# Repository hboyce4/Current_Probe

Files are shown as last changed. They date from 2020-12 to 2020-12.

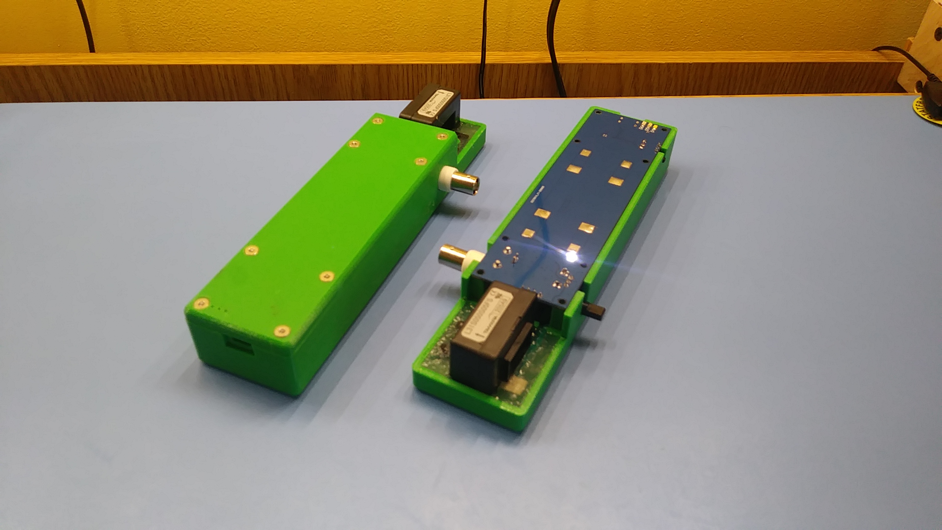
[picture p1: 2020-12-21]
Photos/20201220_143055.jpg

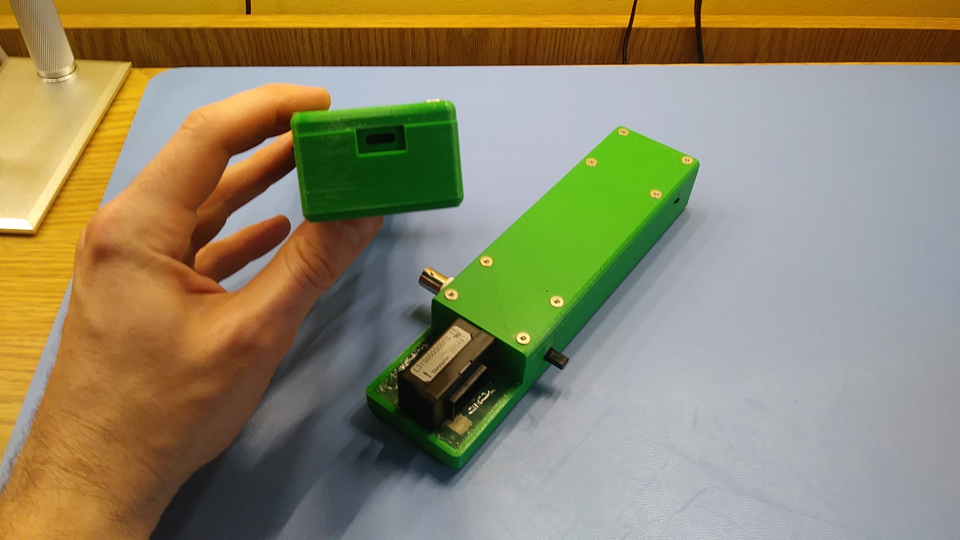
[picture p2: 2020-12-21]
Photos/20201220_143459.jpg

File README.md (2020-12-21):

Current_Probe

A poor man's current probe

Quick specs:

Sensor rated at +-50A nominal, although according to the datasheet it will easily do +-100A. The rest of the circuit is designed for +-100A.
Bandwidth: DC to 100kHz (-3dB) dictated by the sensor.
Batteries: 2P1S 18650 li-ion. 500mA charging current via USB.
Sensivity: 10A/V
Output impedance: 50ohms

Free to use for educational/hobby purposes

Hugo Boyce

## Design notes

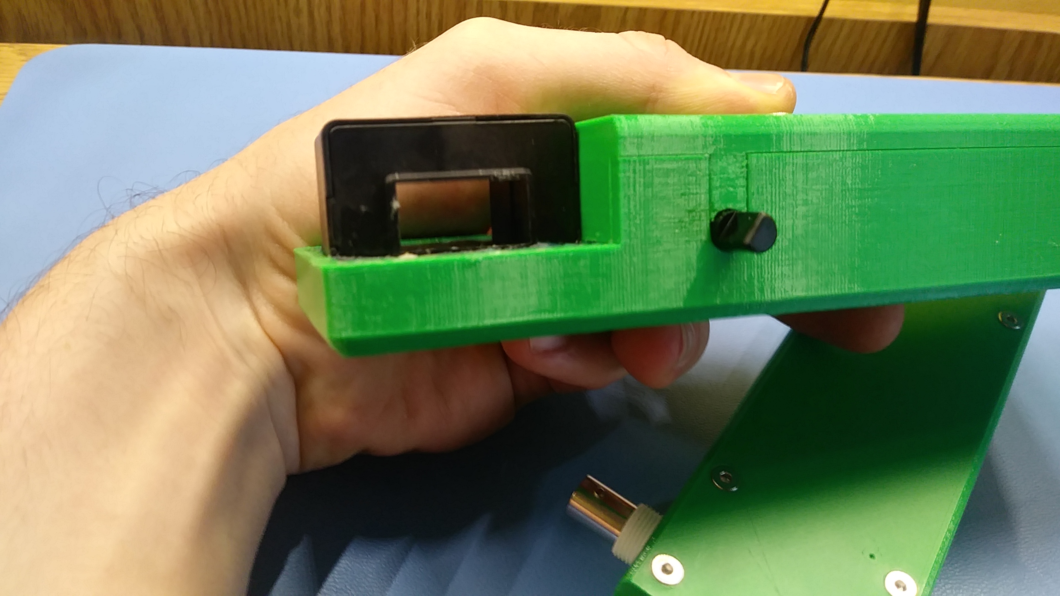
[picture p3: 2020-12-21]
Photos/20201220_143514_HDR.jpg

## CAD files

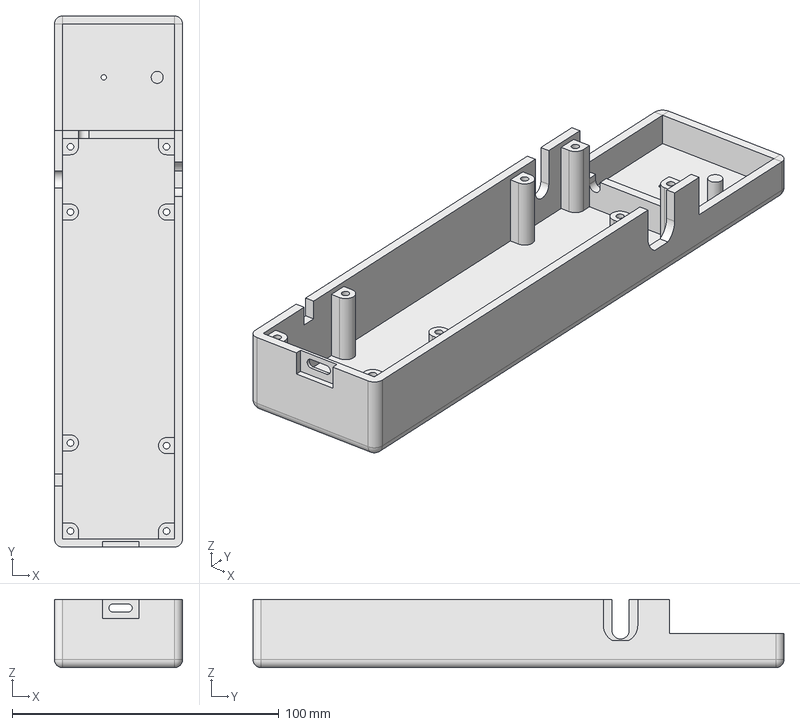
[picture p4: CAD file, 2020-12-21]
Enclosure/Bottom_half.step
48.0 x 199.0 x 25.6 mm

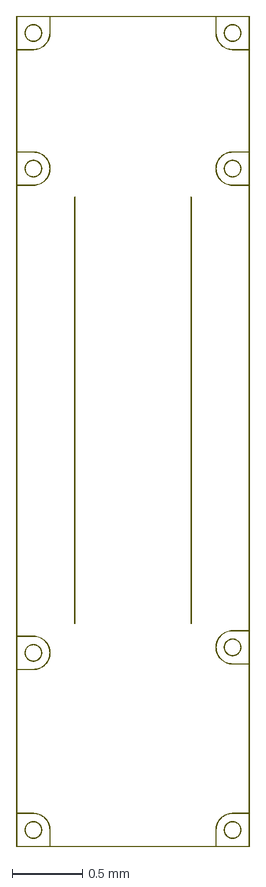
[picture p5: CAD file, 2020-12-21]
Enclosure/PCB - Current_Probe_V0.1_Mechanical_outline.dxf
1.66 x 5.91 mm

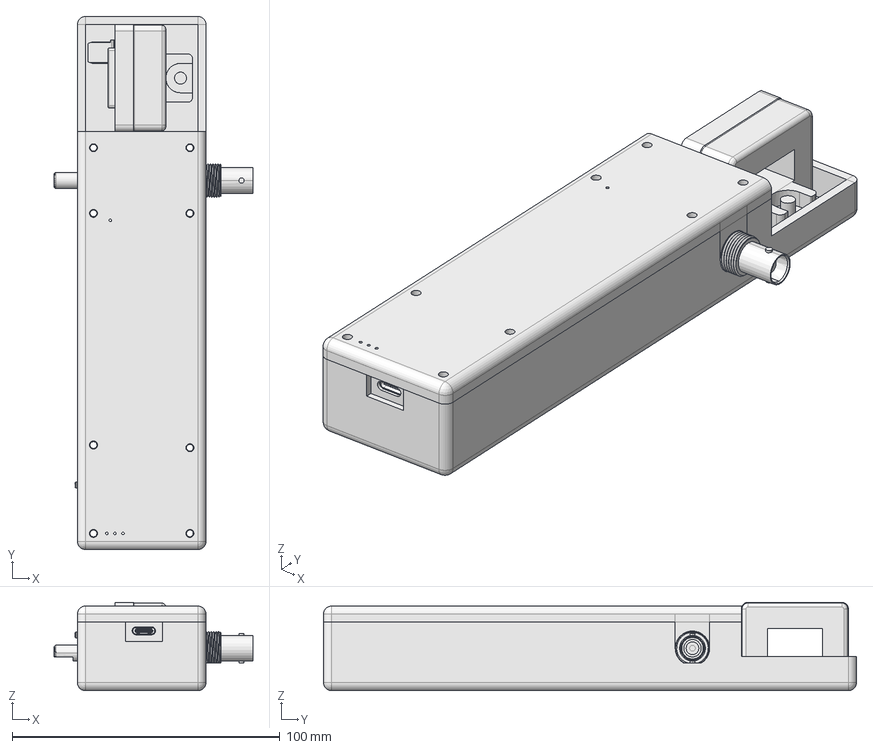
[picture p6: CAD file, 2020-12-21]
Enclosure/Current_Probe_EnclosureV0.1.5.FCStd
74.3 x 199.0 x 33.0 mm
Bottom_half
Board
Open_CASCADE_STEP_translator_6.8_2.1.1
lead
lead001
Open_CASCADE_STEP_translator_6.8_2.1.002
lead002
lead003
Open_CASCADE_STEP_translator_6.8_2.1
Open_CASCADE_STEP_translator_6.8_2.2.1
Thermal_Shape
Open_CASCADE_STEP_translator_6.8_2.4.1
Open_CASCADE_STEP_translator_6.8_2.4.002
Open_CASCADE_STEP_translator_6.8_2.4.003
Open_CASCADE_STEP_translator_6.8_2.4.004
Open_CASCADE_STEP_translator_6.8_2.4.005
Open_CASCADE_STEP_translator_6.8_2.4.006
Open_CASCADE_STEP_translator_6.8_2.4.007
Open_CASCADE_STEP_translator_6.8_2.4.008
Open_CASCADE_STEP_translator_6.8_2.4.009
Open_CASCADE_STEP_translator_6.8_2.4.010
Open_CASCADE_STEP_translator_6.8_1.1
Open_CASCADE_STEP_translator_6.8_1.2.1
Thermal_Shape001
Open_CASCADE_STEP_translator_6.8_1.4.1
Open_CASCADE_STEP_translator_6.8_1.4.002
Open_CASCADE_STEP_translator_6.8_1.4.003
Open_CASCADE_STEP_translator_6.8_1.4.004
Open_CASCADE_STEP_translator_6.8_1.4.005
Open_CASCADE_STEP_translator_6.8_1.4.006
Open_CASCADE_STEP_translator_6.8_1.4.007
Open_CASCADE_STEP_translator_6.8_1.4.008
Open_CASCADE_STEP_translator_6.8_1.4.009
Open_CASCADE_STEP_translator_6.8_1.4.010
Open_CASCADE_STEP_translator_6.8_1.4.011
Open_CASCADE_STEP_translator_6.8_1.4.012
Open_CASCADE_STEP_translator_6.8_1.4.013
Open_CASCADE_STEP_translator_6.8_1.4.014
Open_CASCADE_STEP_translator_6.8_1.4.015
Open_CASCADE_STEP_translator_6.8_1.4.016
Open_CASCADE_STEP_translator_6.8_1.4.017
Open_CASCADE_STEP_translator_6.8_1.4.018
Open_CASCADE_STEP_translator_6.8_1.4.019
Open_CASCADE_STEP_translator_6.8_1.4.020
Open_CASCADE_STEP_translator_6.8_1.4.021
Open_CASCADE_STEP_translator_6.8_1.4.022
Open_CASCADE_STEP_translator_6.8_1.4.023
Open_CASCADE_STEP_translator_6.8_1.4.024
Keystone-254-Battery_Clip
Keystone-254-Battery_Clip001
Keystone-254-Battery_Clip002
Keystone-254-Battery_Clip003
Extruded
Extruded001
Extruded002
Extruded003
Extruded004
Extruded005
Extruded006
Extruded007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

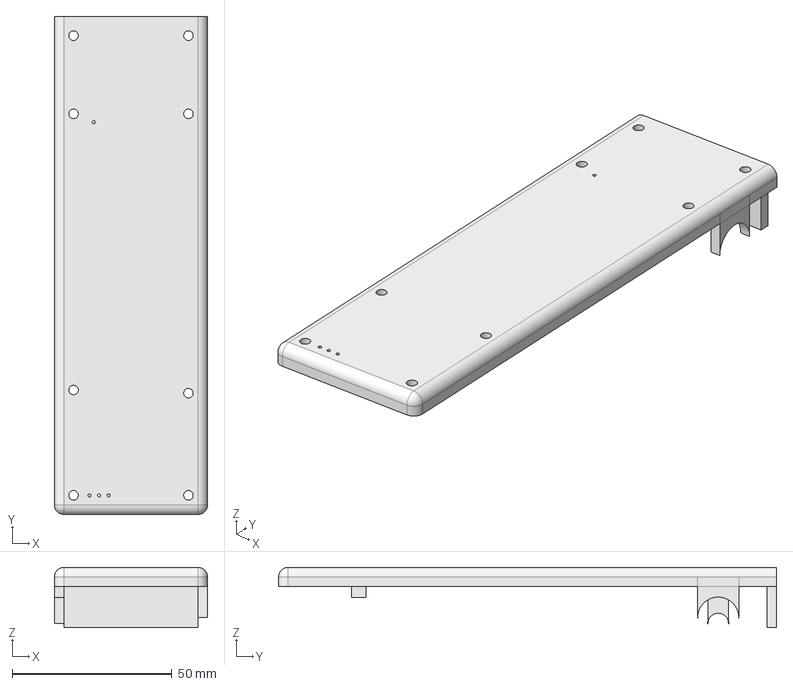
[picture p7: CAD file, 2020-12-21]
Enclosure/Top_half.step
48.0 x 156.0 x 18.9 mm

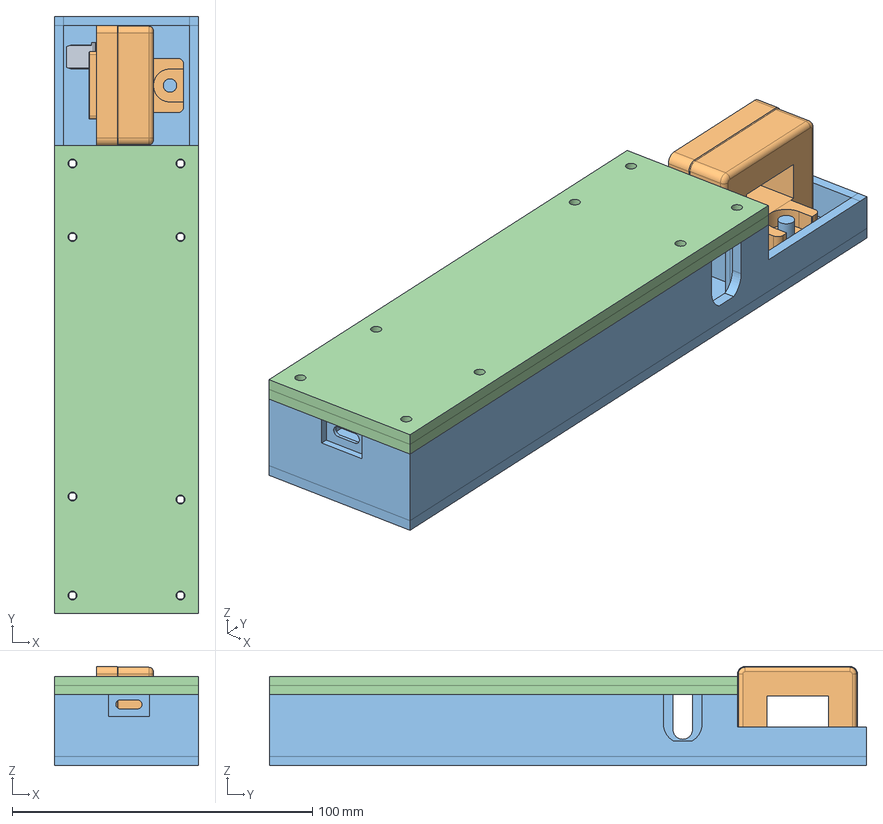
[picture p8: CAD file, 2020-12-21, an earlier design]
Enclosure/Current_Probe_EnclosureV0.1.FCStd
48.0 x 199.0 x 33.0 mm
Bottom_half
Top_half

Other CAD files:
Enclosure/PCB_DXF_With_measurements.FCStd
Enclosure/Bottom_half.stl
Enclosure/Top_half.stl

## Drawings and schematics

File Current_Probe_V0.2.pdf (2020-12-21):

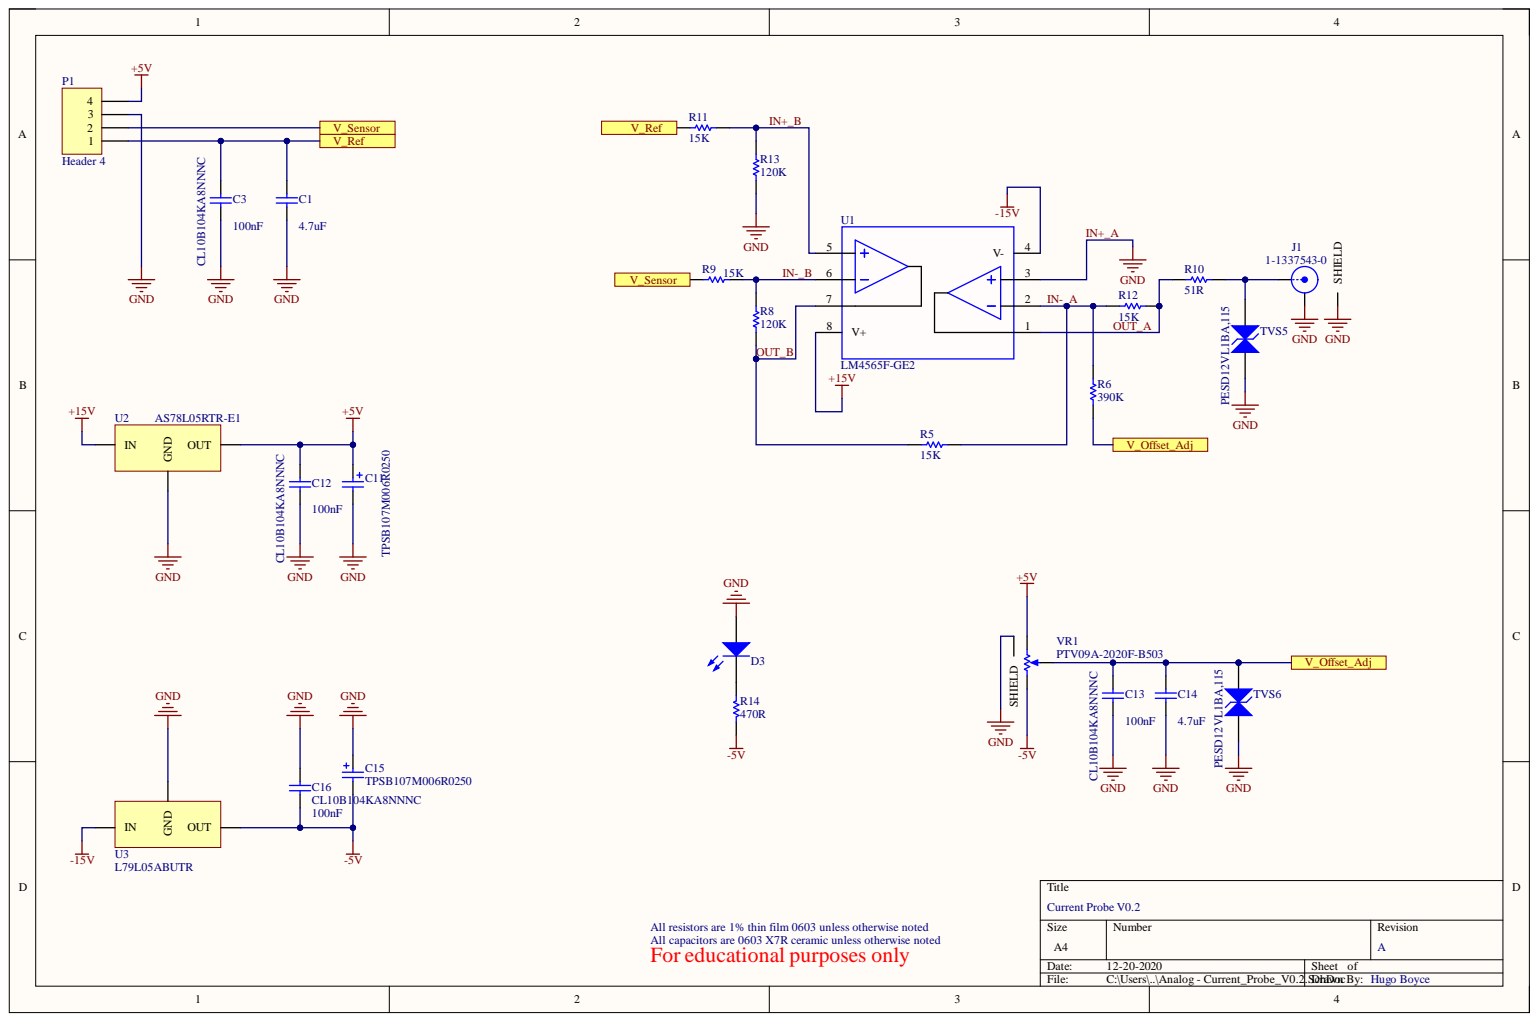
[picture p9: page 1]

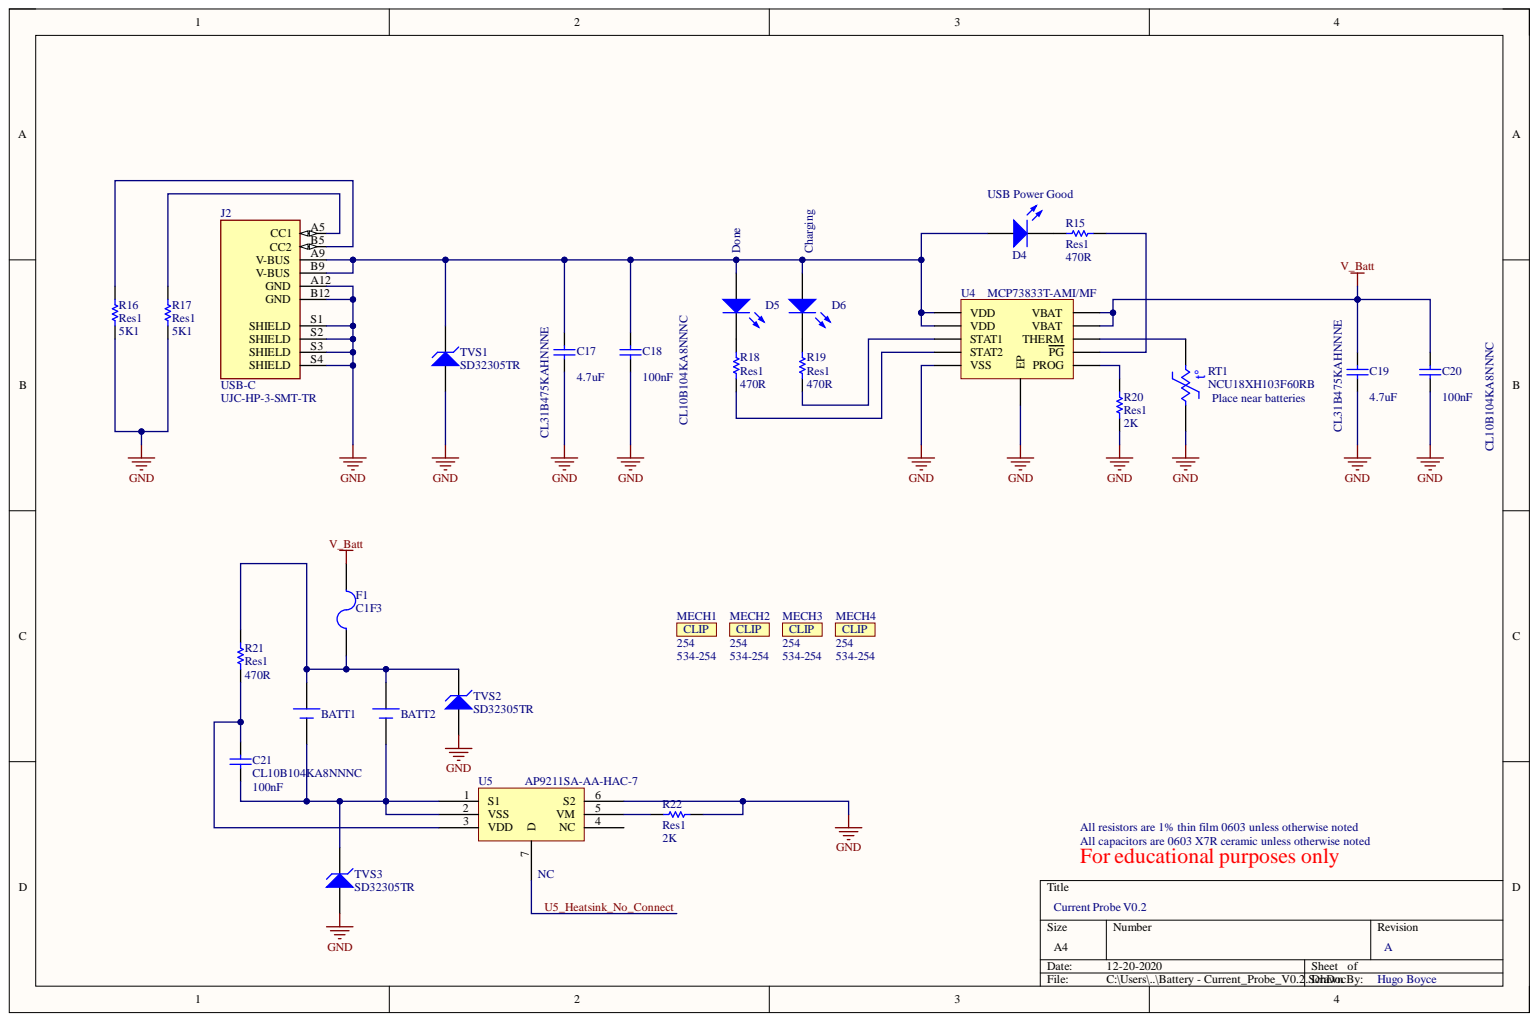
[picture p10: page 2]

2 | | R2 2

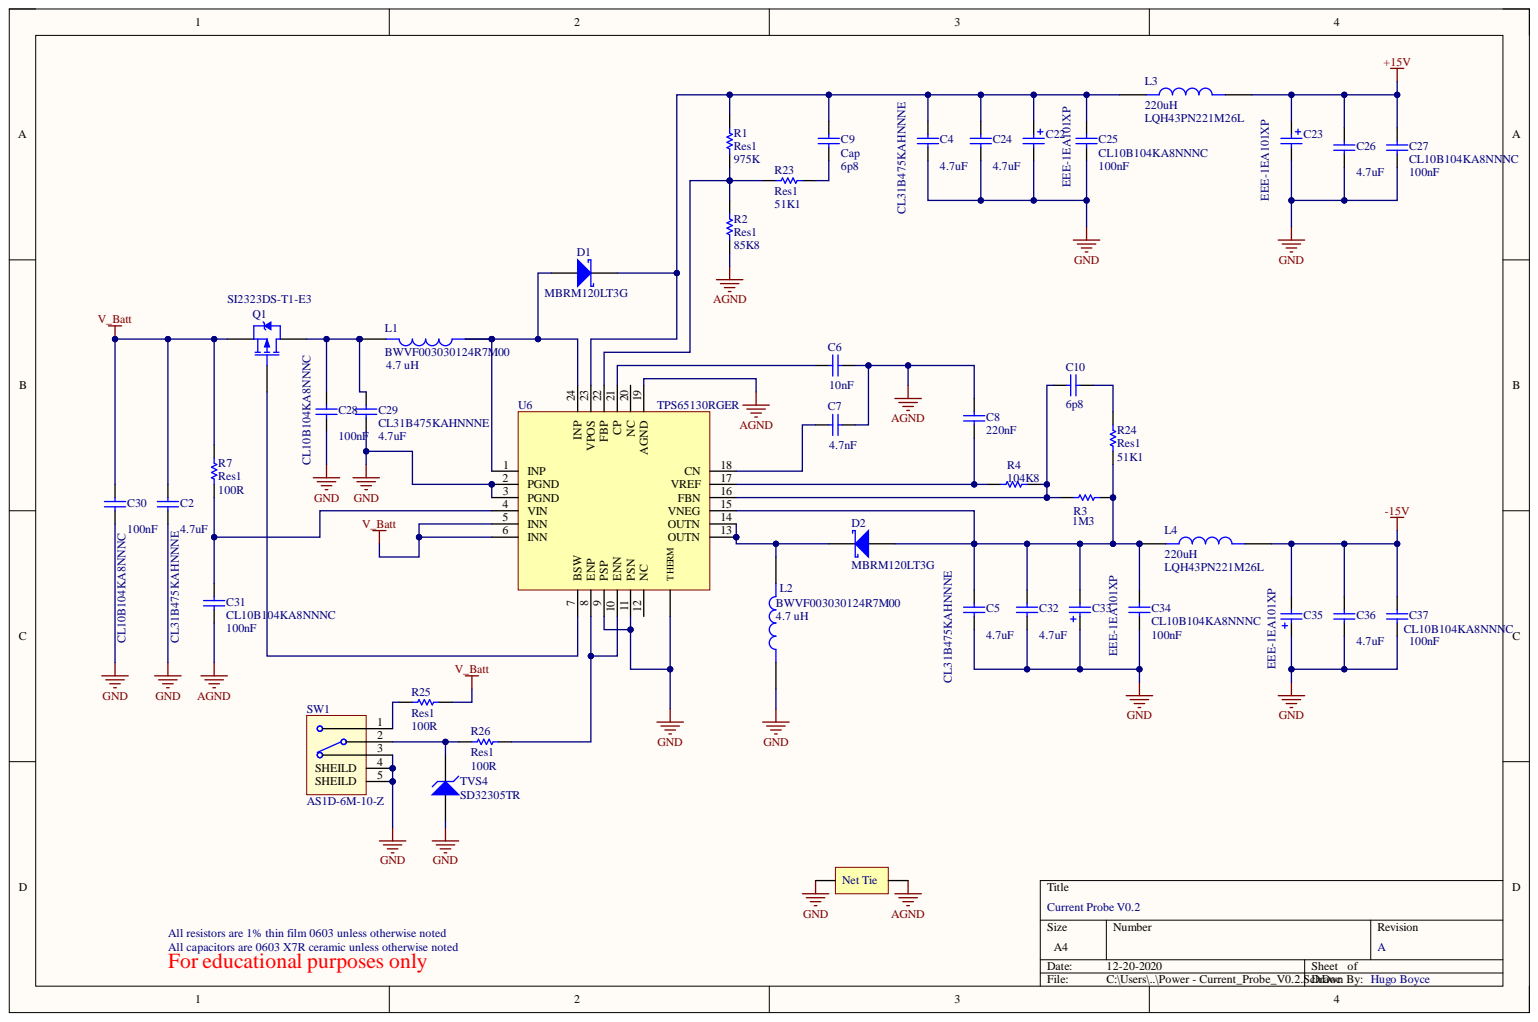
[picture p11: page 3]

AGND 19 NC 20 CP 21 FBP 22 VPOS 23 INP 24

PGND 2 | | 13 OUTN 14 VNEG 15 FBN 16 VREF 17 CN 18

INP 1 | OUTN

Res1 100R

INN 5
INN 6

All resistors are 1% thin film 0603 unless otherwise noted
All capacitors are 0603 X7R ceramic unless otherwise noted

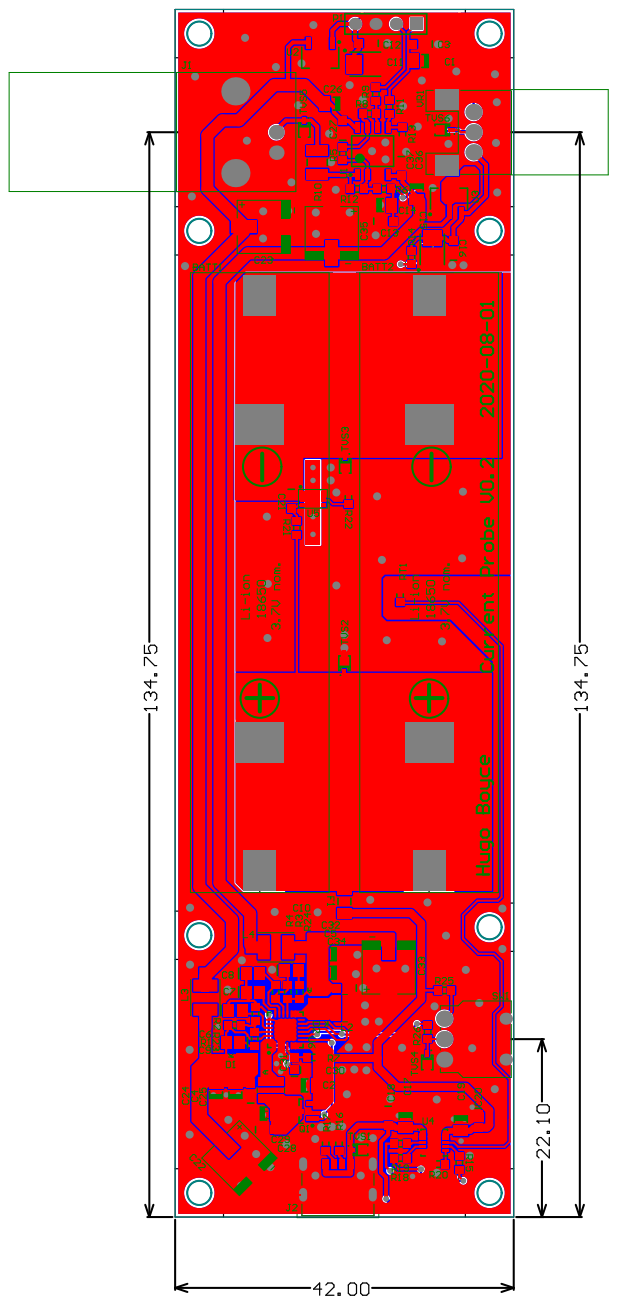
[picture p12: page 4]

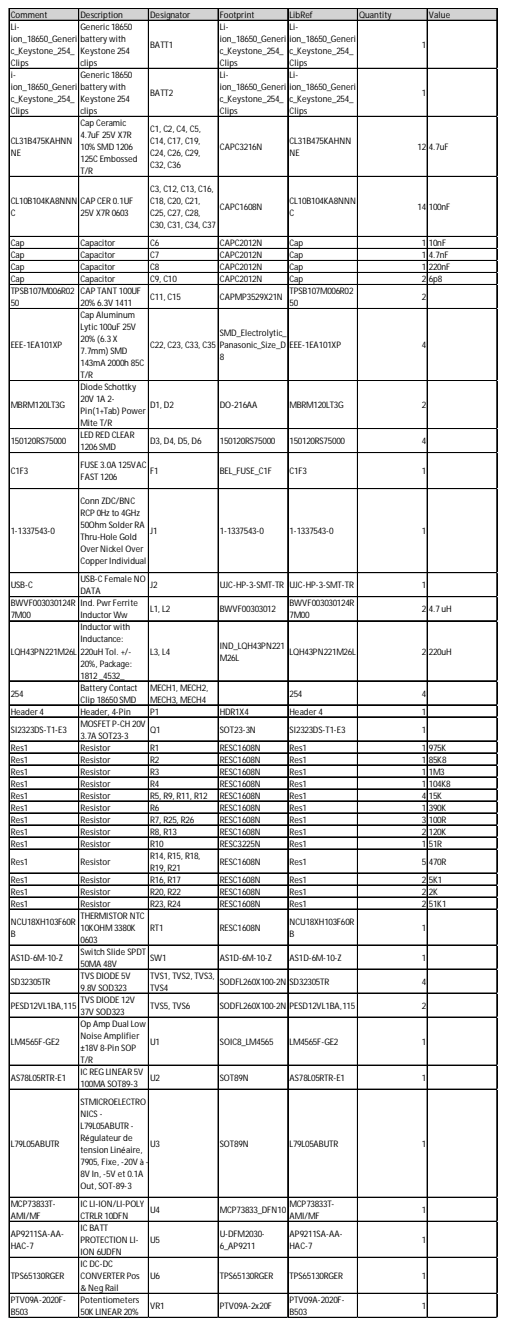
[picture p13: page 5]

Comment | Description | Designator | Footprint | LibRef | Quantity | Value
Li-ion_18650_Generi c_Keystone_254_ Clips | Generic 18650 battery with Keystone 254 clips | BATT1 | Li-ion_18650_Generi c_Keystone_254_ Clips | Li-ion_18650_Generi c_Keystone_254_ Clips

i-ion_18650_Generi c_Keystone_254_ Clips | Generic 18650 battery with Keystone 254 clips | BATT2 | Li-ion_18650_Generi c_Keystone_254_ Clips | Li-ion_18650_Generi c_Keystone_254_ Clips | 1

CL31B475KAHNN NE | Cap Ceramic 4.7uF 25V X7R 10% SMD 1206 125C Embossed T/R | C1, C2, C4, C5, C14, C17, C19, C24, C26, C29, C32, C36 | CAPC3216N | CL31B475KAHNN NE | 12 4.7uF

CL10B104KA8NNN C | CAP CER 0.1UF 25V X7R 0603 | C3, C12, C13, C16, C18, C20, C21, C25, C27, C28, C30, C31, C34, C37 | CAPC1608N | CL10B104KA8NNN C | 14 100nF

Cap | Capacitor | C6 | CAPC2012N | Cap | 1 10nF
Cap | Capacitor | C7 | CAPC2012N | Cap | 1 4.7nF
Cap | Capacitor | C8 | CAPC2012N | Cap | 1 220nF
Cap | Capacitor | C9, C10 | CAPC2012N | Cap | 2 6p8
TPSB107M006R02 50 | CAP TANT 100UF 20% 6.3V 1411 | C11, C15 | CAPMP3529X21N | TPSB107M006R02 50 | 2

EEE-1EA101XP | Cap Aluminum Lytic 100uF 25V 20% (6.3 X 7.7mm) SMD 143mA 2000h 85C T/R | C22, C23, C33, C35 | SMD_Electrolytic_ Panasonic_Size_D 8 | EEE-1EA101XP | 4

MBRM120LT3G | Diode Schottky 20V 1A 2-Pin(1+Tab) Power Mite T/R | D1, D2 | DO-216AA | MBRM120LT3G | 2

150120RS75000 | LED RED CLEAR 1206 SMD | D3, D4, D5, D6 | 150120RS75000 | 150120RS75000 | 4

C1F3 | FUSE 3.0A 125VAC FAST 1206 | F1 | BEL_FUSE_C1F | C1F3 | 1

1-1337543-0 | Conn ZDC/BNC RCP 0Hz to 4GHz 50Ohm Solder RA Thru-Hole Gold Over Nickel Over Copper Individual | J1 | 1-1337543-0 | 1-1337543-0 | 1

USB-C | USB-C Female NO DATA | J2 | UJC-HP-3-SMT-TR | UJC-HP-3-SMT-TR | 1

BWVF003030124R 7M00 | Ind. Pwr Ferrite Inductor Ww | L1, L2 | BWVF00303012 | BWVF003030124R 7M00 | 2 4.7 uH

LQH43PN221M26L | Inductor with Inductance: 220uH Tol. +/-20%, Package: 1812 _4532_ | L3, L4 | IND_LQH43PN221 M26L | LQH43PN221M26L | 2 220uH

254 | Battery Contact Clip 18650 SMD | MECH1, MECH2, MECH3, MECH4 | | 254 | 4

Header 4 | Header, 4-Pin | P1 | HDR1X4 | Header 4 | 1
SI2323DS-T1-E3 | MOSFET P-CH 20V 3.7A SOT23-3 | Q1 | SOT23-3N | SI2323DS-T1-E3 | 1

Res1 | Resistor | R1 | RESC1608N | Res1 | 1 975K
Res1 | Resistor | R2 | RESC1608N | Res1 | 1 85K8
Res1 | Resistor | R3 | RESC1608N | Res1 | 1 1M3
Res1 | Resistor | R4 | RESC1608N | Res1 | 1 104K8
Res1 | Resistor | R5, R9, R11, R12 | RESC1608N | Res1 | 4 15K
Res1 | Resistor | R6 | RESC1608N | Res1 | 1 390K
Res1 | Resistor | R7, R25, R26 | RESC1608N | Res1 | 3 100R
Res1 | Resistor | R8, R13 | RESC1608N | Res1 | 2 120K
Res1 | Resistor | R10 | RESC3225N | Res1 | 1 51R
Res1 | Resistor | R14, R15, R18, R19, R21 | RESC1608N | Res1 | 5 470R

Res1 | Resistor | R16, R17 | RESC1608N | Res1 | 2 5K1
Res1 | Resistor | R20, R22 | RESC1608N | Res1 | 2 2K
Res1 | Resistor | R23, R24 | RESC1608N | Res1 | 2 51K1
NCU18XH103F60R B | THERMISTOR NTC 10KOHM 3380K 0603 | RT1 | RESC1608N | NCU18XH103F60R B | 1

AS1D-6M-10-Z | Switch Slide SPDT 50MA 48V | SW1 | AS1D-6M-10-Z | AS1D-6M-10-Z | 1

SD32305TR | TVS DIODE 5V 9.8V SOD323 | TVS1, TVS2, TVS3, TVS4 | SODFL260X100-2N | SD32305TR | 4

PESD12VL1BA,115 | TVS DIODE 12V 37V SOD323 | TVS5, TVS6 | SODFL260X100-2N | PESD12VL1BA,115 | 2

LM4565F-GE2 | Op Amp Dual Low Noise Amplifier ±18V 8-Pin SOP T/R | U1 | SOIC8_LM4565 | LM4565F-GE2 | 1

AS78L05RTR-E1 | IC REG LINEAR 5V 100MA SOT89-3 | U2 | SOT89N | AS78L05RTR-E1 | 1

L79L05ABUTR | STMICROELECTRO NICS -L79L05ABUTR -Régulateur de tension Linéaire, 7905, Fixe, -20V à -8V In, -5V et 0.1A Out, SOT-89-3 | U3 | SOT89N | L79L05ABUTR | 1

MCP73833T-AMI/MF | IC LI-ION/LI-POLY CTRLR 10DFN | U4 | MCP73833_DFN10 MCP73833T- | AMI/MF | 1

AP9211SA-AA-HAC-7 | IC BATT PROTECTION LI-ION 6UDFN | U5 | U-DFM2030-6_AP9211 | AP9211SA-AA-HAC-7 | 1

TPS65130RGER | IC DC-DC CONVERTER Pos & Neg Rail | U6 | TPS65130RGER | TPS65130RGER | 1

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

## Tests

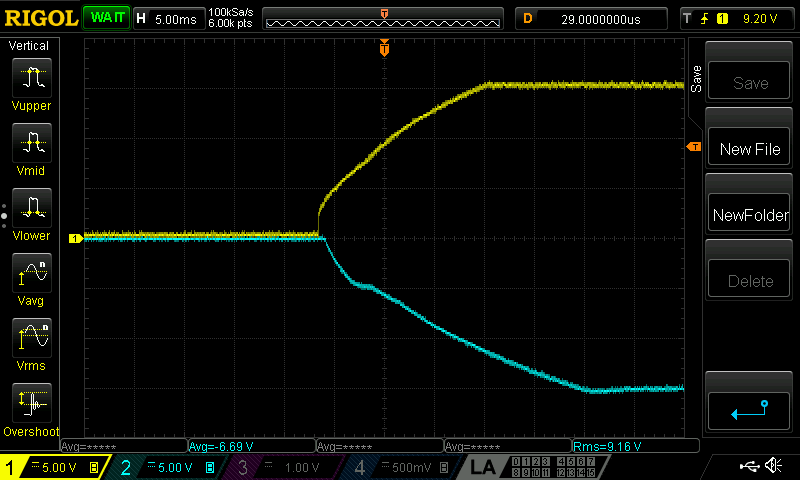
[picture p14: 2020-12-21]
Validation/Supplies_rise_time_15V_with_power_saving.png

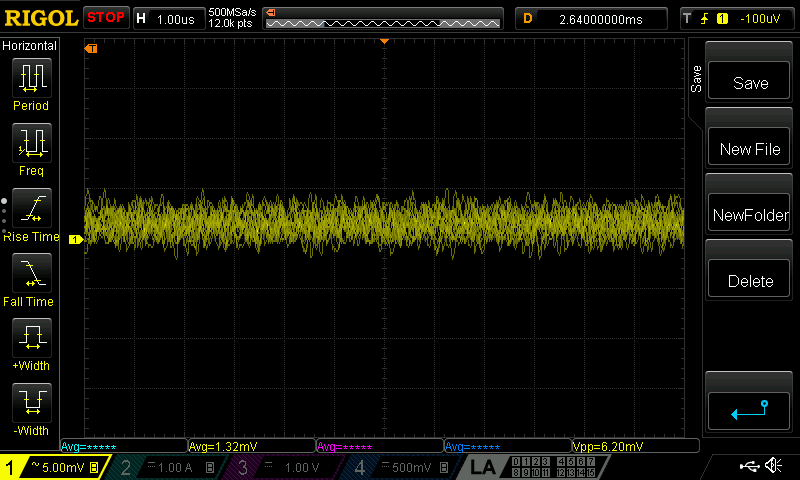
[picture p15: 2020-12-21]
Validation/Noise_positive_post_filter.png

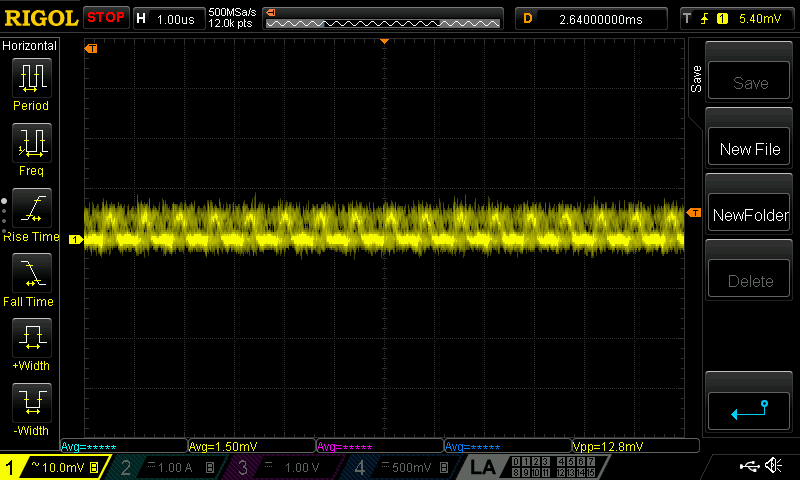
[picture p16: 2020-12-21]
Validation/Noise_positive_pre_filter.png
